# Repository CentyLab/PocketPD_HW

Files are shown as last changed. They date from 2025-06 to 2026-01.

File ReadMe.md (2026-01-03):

Shield: [][cc-by-sa]

This work is licensed under a
[Creative Commons Attribution-ShareAlike 4.0 International License][cc-by-sa].

[][cc-by-sa]

[cc-by-sa]: http://creativecommons.org/licenses/by-sa/4.0/
[cc-by-sa-image]: https://licensebuttons.net/l/by-sa/4.0/88x31.png
[cc-by-sa-shield]: https://img.shields.io/badge/License-CC%20BY--SA%204.0-lightgrey.svg

# Quick links
- PocketPD's Firmware - [GitHub](https://github.com/CentyLab/PocketPD)
- PocketPD's Project Page - [Hackaday.io](https://hackaday.io/project/194295-pocketpd-usb-c-portable-bench-power-supply)
- CentyLab website - [CentyLab.com](https://centylab.com)
- CrowdSupply Page - [CrowdSupply.com](https://www.crowdsupply.com/centylab/pocketpd)

# Hardware Overview
- Design Files - .kicad_*
	- KiCad design files
- Gerber files - _Gerber.zip; _Gerber.pdf
    - PCB copper and drill file for fabrication
- Schematic file - _Schematic.pdf
    - Schematic in PDF format
- BOMs - _bom.cvs
    - Bill of material for the PCBA and also the unit assembly for additional parts
- 3Ds files
    - Model ready for 3D printing for housing and encoder knob. You can view the models online directly on GitHub. Else, check out free online viewer [3dviewer.net](https://3dviewer.net/)
	- 3D model for the whole PocketPD PCB and Connector if you would like to model your own case.

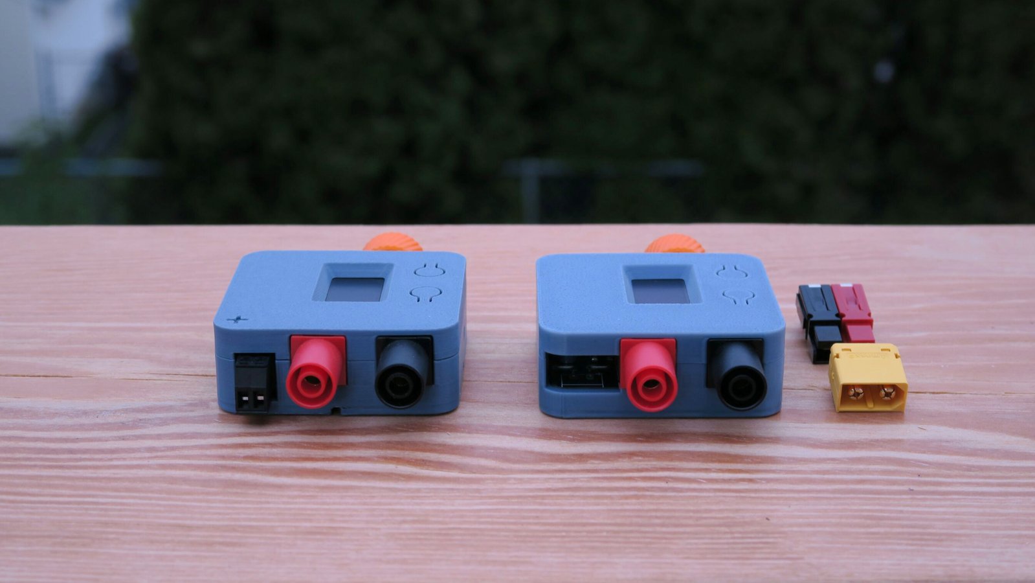
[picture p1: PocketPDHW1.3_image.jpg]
BothVersionImage


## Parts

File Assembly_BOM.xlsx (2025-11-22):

Description | Quatity | Part # | Estimate price | Note | Suggested Supplier
M2 x 4mm, flat head | 4 |  |  | Self taping, pan head or counter sunk head both work
M2 x 10mm, flat head | 4 |  |  | Self taping, pan head or counter sunk head both work
Neodium N35 Magnet 15x5mm, flat disc | 1 |  |  | No glue is needed
Thermal double-sided tape, 15x5mm | 1 |  |  | No exact dimension is needed. Need to cover most of the magnet
OLED WHITE screen 0.96 inch I2C, exact dimension + pin layout attached | 1 |  | 3 |  | https://www.aliexpress.us/item/3256806076593949.html
EC11J-5DM20P1ZY15F7, Encoder | 1 | EC11J | 1.65 |  | https://www.aliexpress.us/item/3256807905633617.html
1x2P Black Plug P=3.81mm Pluggable System Terminal Block ROHS | 1 | C430322 (https://www.lcsc.com/product-detail/Pluggable-System-Terminal-Block_DORABO-DB2EK-3-81-2P-BK-S_C430322.html) | 0.1828 | LCSC/Mouser/Digikey
Anderson Powerpole PR45 | 1 | ASMPR45-1X2-RK | 3.95 | Order on Mouser/Digikey
XT60 Male Right Angle | 1 | XT60PW-M | 0.58
Encoder Knob | 1 |  |  | 3D printed, PETG/ABS, Orange
Top case | 1 |  |  | 3D printed, PETG/ABS, Dark Gray or Blue Gray
Bottom case | 1 |  |  | 3D printed, PETG/ABS, Dark Gray or Blue Gray

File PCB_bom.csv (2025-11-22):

Designator | Footprint | Quantity | Value | LCSC Part #
C1, C10, C11, C12, C14, C19, C2, C21, C24, C26, C4, C5, C7, C8, C9 | 402 | 15 | 100nF | C1525
C13, C18, C6 | 402 | 3 | 2.2uF | C12530
C15, C22, C23 | 1210 | 3 | 10u | C138687
C16, C20 | 402 | 2 | 30pF | C1570
C17 | CP_Elec_6.3x7.7 | 1 | 100u | C178560
C27, C3 | 805 | 2 | 1u | C28323
C28, C30 | 603 | 2 | 100n | C14663
D1 | SON50P100X255X50-10N | 1 | TPD4E05U06DQAR | C138714
D2 | D_SMA | 1 | D_Schottky | C8678
D3, D6 | D_SMA | 2 | D_TVS | C19077540
D5 | 603 | 1 | RED | C2286
J1 | USB_C | 1 | USB_C_Receptacle | C963411
J4 | Conn_OLED_PocketPD | 1 | OLED | C20071191
J6 | Banana_Cliff_FCR7350R_S16N-PC_Horizontal | 1 | BananaP | C7437326
J8 | Banana_Cliff_FCR7350B_S16N-PC_Horizontal | 1 | BananaN | C7437327
R1 | 1206 | 1 | 5mR | C2988648
R10, R11 | 402 | 2 | 27R | C138021
R12, R18, R20, R26, R27, R29, R30 | 402 | 7 | 1k | C11702
R13, R14, R25 | 402 | 3 | 10R | C25077
R15, R16, R17, R19, R22, R28, R6, R7, R9 | 402 | 9 | 10k | C25744
R2, R21, R23, R24, R3, R4, R5, R8 | 402 | 8 | 5.1k | C25905
SW1 | RotaryEncoder_EC11B_SW_Horizontal | 1 | RotaryEncoder_Switch
SW2 | Button_6.2x6.2x12mm | 1 | SW_Select | C2762973
SW4 | Button_6.2x6.2x12mm | 1 | SW_OutPut | C2762973
SW5 | Button-SMD_TS24CA | 1 | SW_Boot | C692458
TH1 | 402 | 1 | Thermistor_NTC | C77131
U1, U6 | VQFN-HR-16 | 2 | LM73100 | C3210761
U2 | QFN-24-1EP_4x4mm_P0.5mm_EP2.6x2.6mm | 1 | AP33772 | C5244513
U3 | QFN-56-1EP_7x7mm_P0.4mm_EP3.2x3.2mm | 1 | RP2040 | C2040
U4 | SOT-23-5 | 1 | AP2204K-3.3 | C112032
U5 | 8-USON | 1 | W25Q16JVUXIQ_TR | C2843335
U7 | VSSOP-10_3x3mm_P0.5mm | 1 | INA226 | C49851
U8 | SOT-353_SC-70-5 | 1 | 74LVC1G17 | C10425
Y1 | Crystal_SMD_3225-4Pin_3.2x2.5mm | 1 | 12MHz | C133334

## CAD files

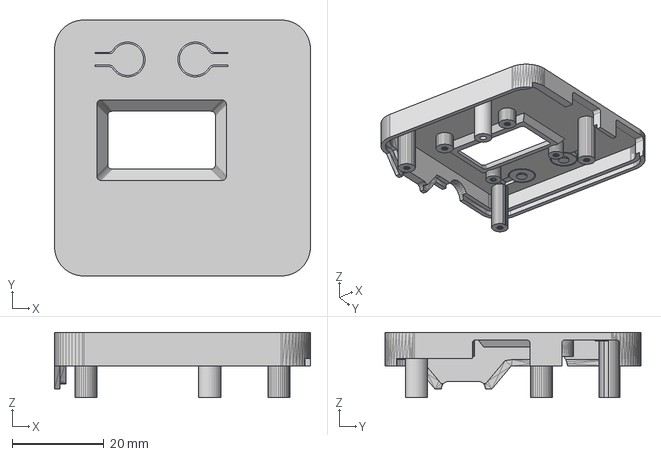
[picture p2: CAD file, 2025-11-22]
AnderonXT60_SKU2/Top_Anderson-XT60.step
55.8 x 55.8 x 14.2 mm

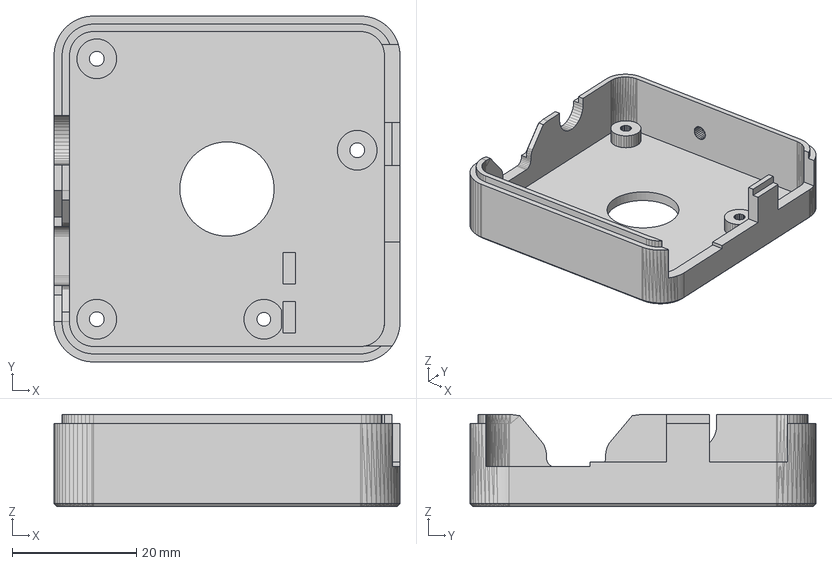
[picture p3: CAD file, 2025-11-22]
AnderonXT60_SKU2/Bottom_Anderson-XT60.step
55.8 x 55.8 x 14.9 mm

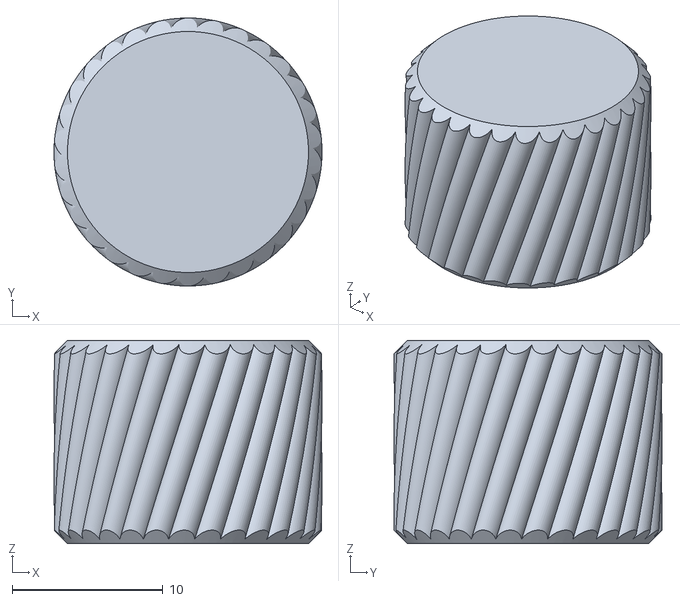
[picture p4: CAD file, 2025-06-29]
AnderonXT60_SKU2/Knob.stl
17.8 x 17.8 x 13.5

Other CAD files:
ScrewTerminal_SKU1/PocketPD_BOT_ScrewTerminal.step
ScrewTerminal_SKU1/PocketPD_TOP_ScrewTerminal.step

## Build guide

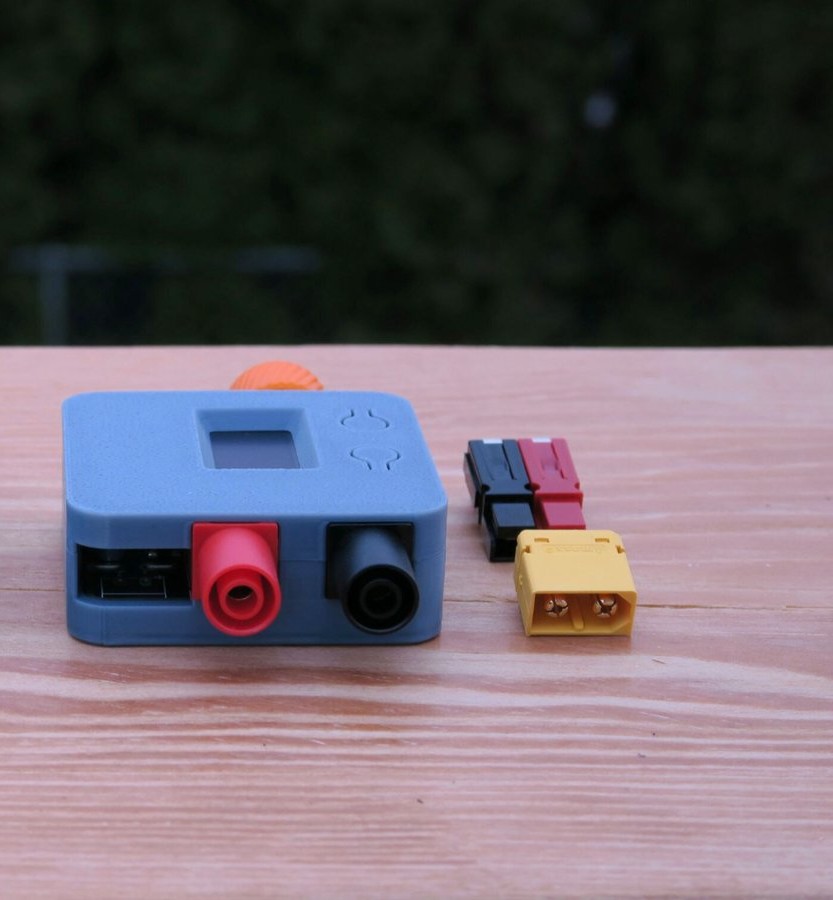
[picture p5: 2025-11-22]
AnderonXT60_SKU2/AndersonXT60_complete_assembly.jpg

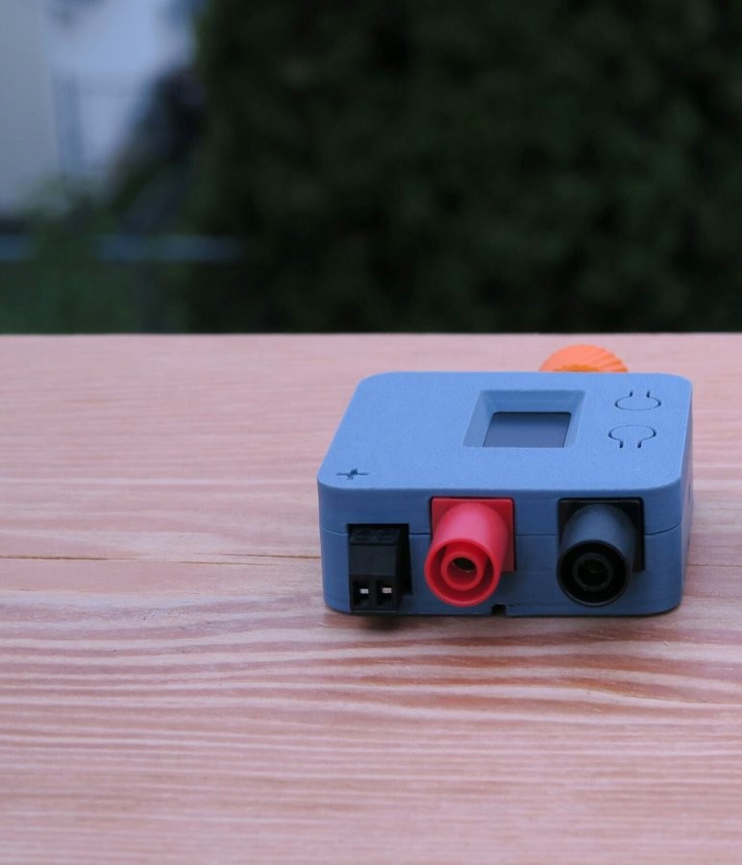
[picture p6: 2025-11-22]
ScrewTerminal_SKU1/ScrewTerm_complete_assembly.jpg

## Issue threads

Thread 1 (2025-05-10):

"pick and place" file

warped-pipe, 2025-05-10:
is this a file that i can make for myself by opening these in kicad? it'd be nice to have, to make ordering via jlpcb easy..

warped-pipe, 2025-05-10:
thank you so much for making the hardware open!

Johaan1314, 2025-05-11:
The cost of ordering and using extended parts from JLCPCB is not worth it. It consists of more than 10 extended parts which is at least $30 of extended part fees, on top of part fees, SMT set-up fees, etc. And that's already the best assumption that all the parts can be found in JLCPCB's extended part list.

It would be great if they can order the kicad SCH and PCB files so one can upload to JLCPCB to verify it for themselves, but I'm fairly certain the costs won't workout for small volumes. It's going to be cheaper to just order from the original website at https://lectronz.com/products/pocketpd

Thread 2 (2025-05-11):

Query: Why Dual LM73100?

Johaan1314, 2025-05-11:
Hi,

not an issue, but I'm curious as to why there are two LM73100? each LM73100 already contains 2 FET for reverse current protection, and each can take the 5A which is the max for PPS right?

Thanks!

CentyLab, 2025-05-11:
The LM73100 get hot fast if pulling 5A through. It get to more than 80C for
one, so we double them up to spread the heat and reduce voltage drop.

The short circuit protection still work with 2 IC in parallel which is nice.

-Centy

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

Johaan1314, 2025-05-11:
Thank you very much for sharing! =)

Closed 2025-05-11.

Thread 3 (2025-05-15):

device models

Willofswan, 2025-05-15:
Thank you very much for sharing. I would like to make one myself. Can you tell me the specific device models of TH1, SW2, SW4?I‘m unable to obtain specific information from the BOM, thank you

Closed 2025-05-15.

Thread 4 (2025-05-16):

[Information] Added a DC barrel plug as _additional_ output into the case.

dreirund, 2025-05-16:
Ahoj,

to let you know: I managed to fit in an additional output connector -- a barrel plug DC connector -- to my PocketPD (Hardware version 1.0):

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

(Note that the barrel plug might not be rated at 5A but only at 2A).

Regards!

CentyLab, 2025-05-16:
@dreirund We are glad that you were able to mod it to your liking!

dreirund, 2025-05-18:
Some suggestions:

* Add somewhere a "user modifications" gallery, where people can share their modifications (wiki?) or where you show modifications which users have made and sent you.

* Maybe in a future PCB revision you can add solder points to the PCB for exactly this kind of modification?

* And maybe, since it is now "proven" that the connector can be added without sacrificing any other connector, you can actually add it in a next design/ offer to add it as an option? (however, the connector won't be soldered to the PCB but screw-mounted to the case, which requires more manual soldering.)

  If you are concerned with the power rating, maybe adding a "[polyfuse](https://en.wikipedia.org/wiki/Resettable_fuse)" and/ or using the sense pin of the barrel plug connector to make the firmware setting an appropriate power limit if a barrel plug is plugged in -- but I have also seen higher power barrel sockets so far, installed in devices (small computers).

Regards!

LIVESKILLER, 2025-08-12:
> 我们很高兴您能够根据自己的喜好对其进行修改！

    I really like your design. Since 0402 components are too difficult to solder, I want to have the PCB assembled by the manufacturer. Could you please provide the coordinate file? Thank you very much!

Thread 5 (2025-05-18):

PD_INT pin is not connected in pcb

ninjaWw, 2025-05-18:
According to the published schematic, pin 36 of RP2040 is defined as PD_INT, and pin 9 of AP33772 is also PD_INT, but these two pins are not connected in the PCB. Is this an error?

CentyLab, 2025-05-19:
Hi @ninjaWw,
This was an oversight. The AP33772 library doesn't utilize the INT pin so we didn't check for connection. At this point, we won't be able to change the current version of the hardware as it already rolled out to production. Luckily, this missing pin won't impact the features provided by the PocketPD firmware.
We have noted the missing connection for future revision if there is more major change to the hardware.

dreirund, 2025-05-19:
> [pin 9 of AP33772 is also PD_INT](#issue-3071221435)

The [datasheet](https://www.diodes.com/datasheet/download/AP33772.pdf) calls pin 9 of AP33772 only "GPIO3". And yes, in the description it says "*For Interrupt Usage*", and further:

> ***I2C Support***
> *The I2C functions of the AP33772 are enabled by three pins—SDA (Pin 4—I2C data), SCL (Pin 5—I2C Clock), and GPIO3 (Pin 9—Interrupt). The host MCU of the TCD, functioning as the I2C master, writes proper contents to the relevant I2C register of the AP33772, working as an I2C slave device, to specify desired power profiles and various protection features. It also accesses the AP33772 for various statuses to take proper actions and maintain normal functions of the TCD during the charging process. \[&hellip;\]*

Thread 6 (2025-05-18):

[Question] What are advantages and drawbacks of 5 mOhm current sensing resistor instead of 10 mOhm?

dreirund, 2025-05-18:
Ahoj,

what benefit and drawback you actually observed with changing the current sensing resistor from 10mOhm to 5mOhm in hardware revision 1.1?

At 5A current, 10 mOhm gives a voltage drop of 0.05V (5mOhm of 0.025V). I suppose this is much less than what the resistance of connectors (and cables) give, _and_ there is also the "ideal diode" + switch LM73100, which has something like 20..30 mOhm of switched-on resistance (or 10..15 mOhm in case you have put the two switches in parallel).

So, what actually are the "real world" advantages, and drawbacks, of 5 mOhm instad of 10 mOhm of this resistor?

I am asking because I could add another 10mOhm SMD resistor on top of the existing one, thus making it 5 mOhm.

(I can think off that 5 mOhm makes current sensing less accurate.)

Regards!

dreirund, 2025-05-19:
> *[With 5mOhm we got a current resolution at 0.5mA \[&hellip;\]](#issuecomment-2889953775)*
> *[We have selected 5mOhm instead of 10mOhm is to reduce the heat generated.](#issuecomment-2889953775)*

Thanks for the answer and clarification!

Closed 2025-05-19.

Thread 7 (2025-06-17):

OVLO of LM7310 connected to GND

Johaan1314, 2025-06-17:
Am hoping to learn from your design. According to the datasheet for LM7310, OVLO (overvoltage lockout) should be connected to a resistor divider between Vin and GND to set the overvoltage protection. But in the schematics OVLO is connected to ground instead. Can you help to educate me please?

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

CentyLab, 2025-06-17:
Hi,
The LM7310 require OVLO to be low enough, and EN high enough to activate
the switch. We soly want the microcontroller to have control of the IC so
we GND the OVLO, allow just EN pin as toggle for the circuit.

If the power source is USBC conpliance, there is a very low chance that
VBUS exceed 20V. And transient (spike higher than 20V) is designed to be
clamped down by TVS diode around input and ouput.
-Centy

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

Closed 2025-06-17.

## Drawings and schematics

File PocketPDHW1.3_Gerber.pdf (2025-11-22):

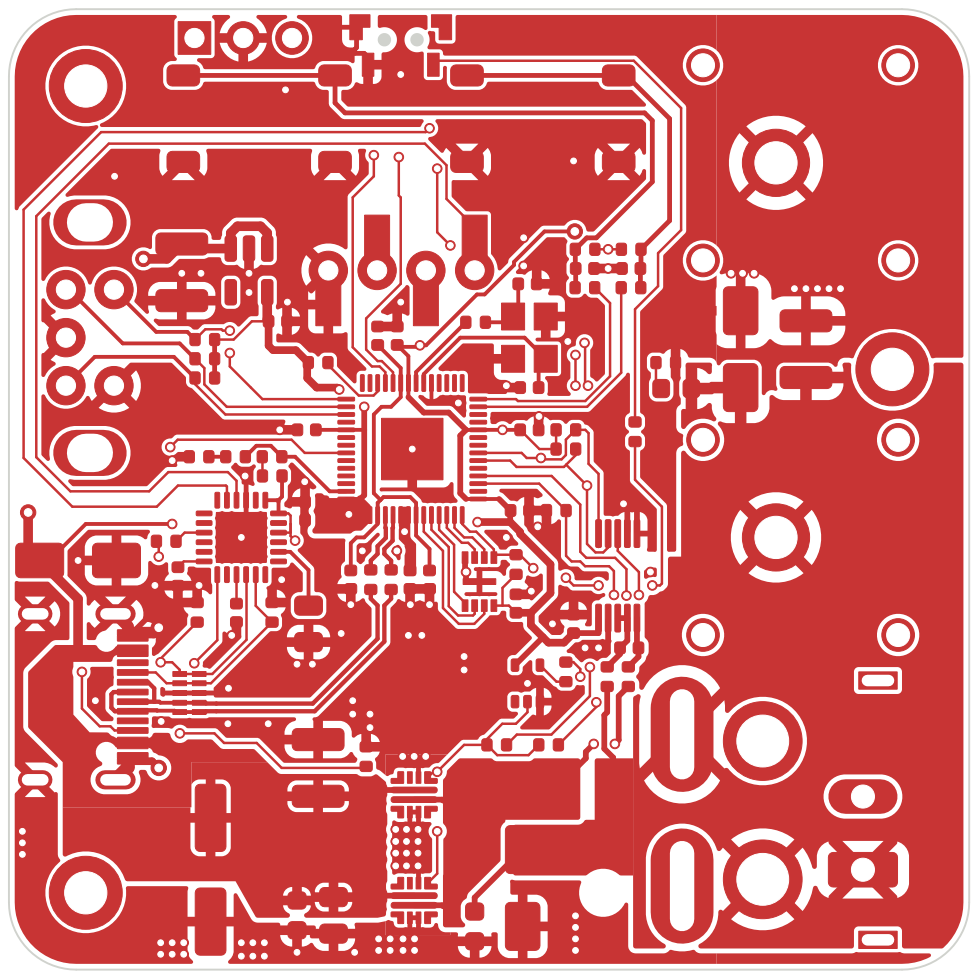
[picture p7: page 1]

Id: 1/7 Title: File: PicoPDSupply.kicad_pcb Sheet:

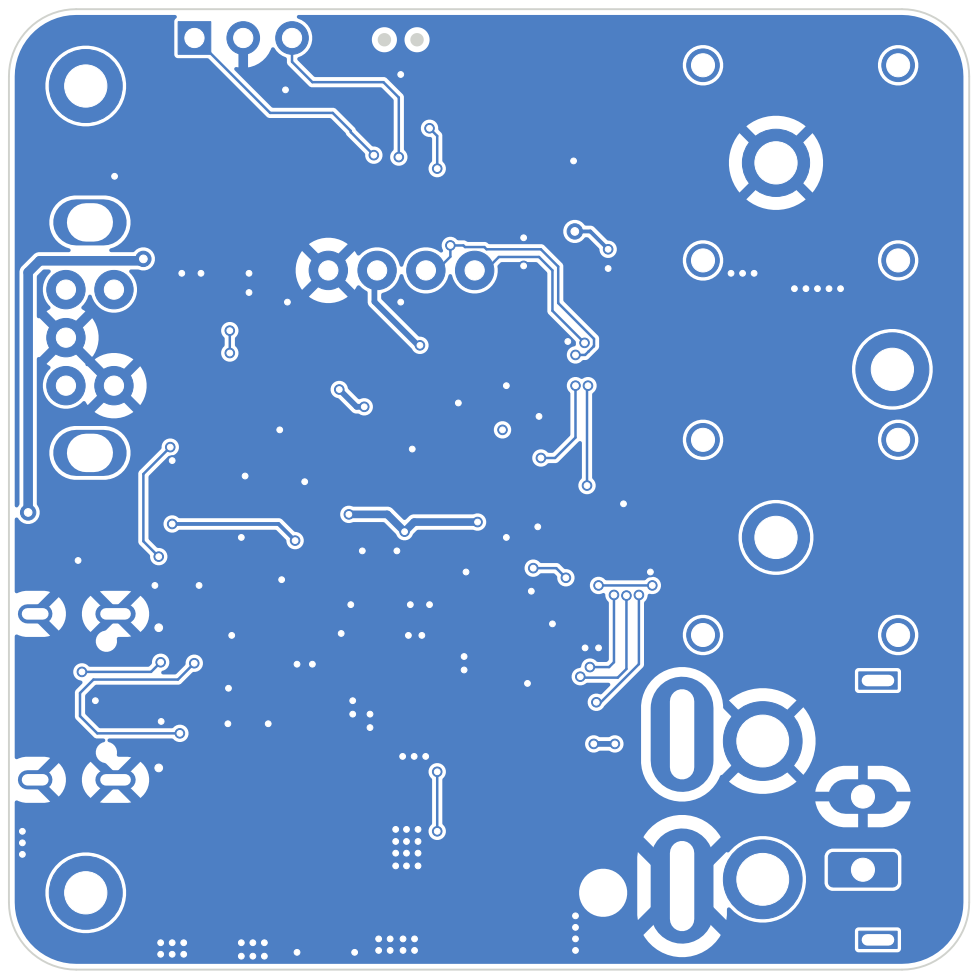
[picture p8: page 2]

Id: 2/7 Title: File: PicoPDSupply.kicad_pcb Sheet:

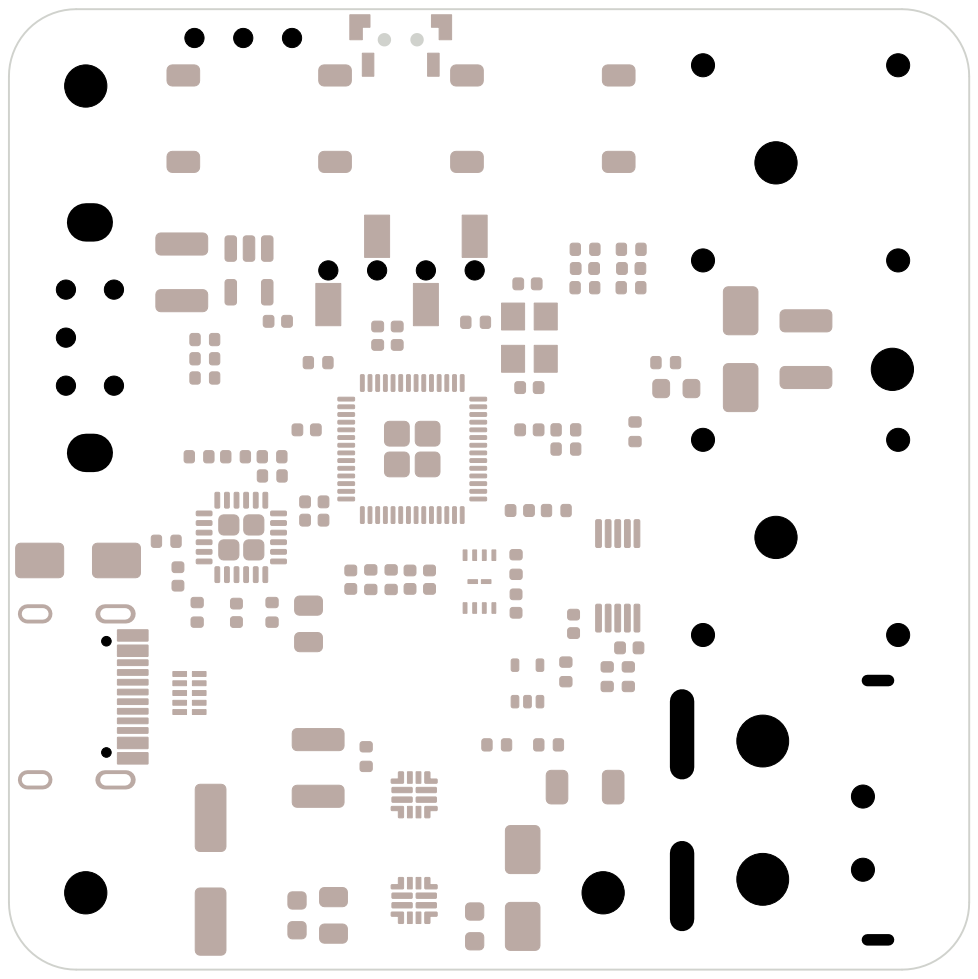
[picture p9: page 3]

Id: 3/7 Title: File: PicoPDSupply.kicad_pcb Sheet:

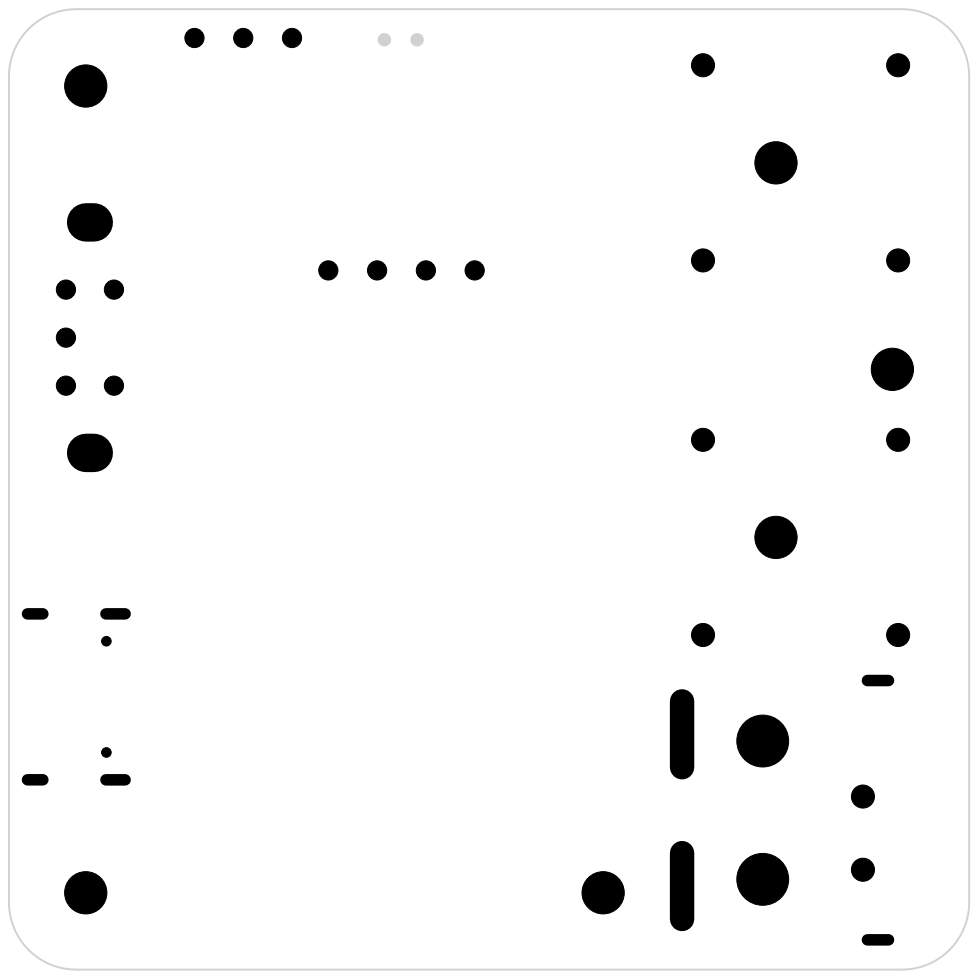
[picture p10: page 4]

Id: 4/7 Title: File: PicoPDSupply.kicad_pcb Sheet:

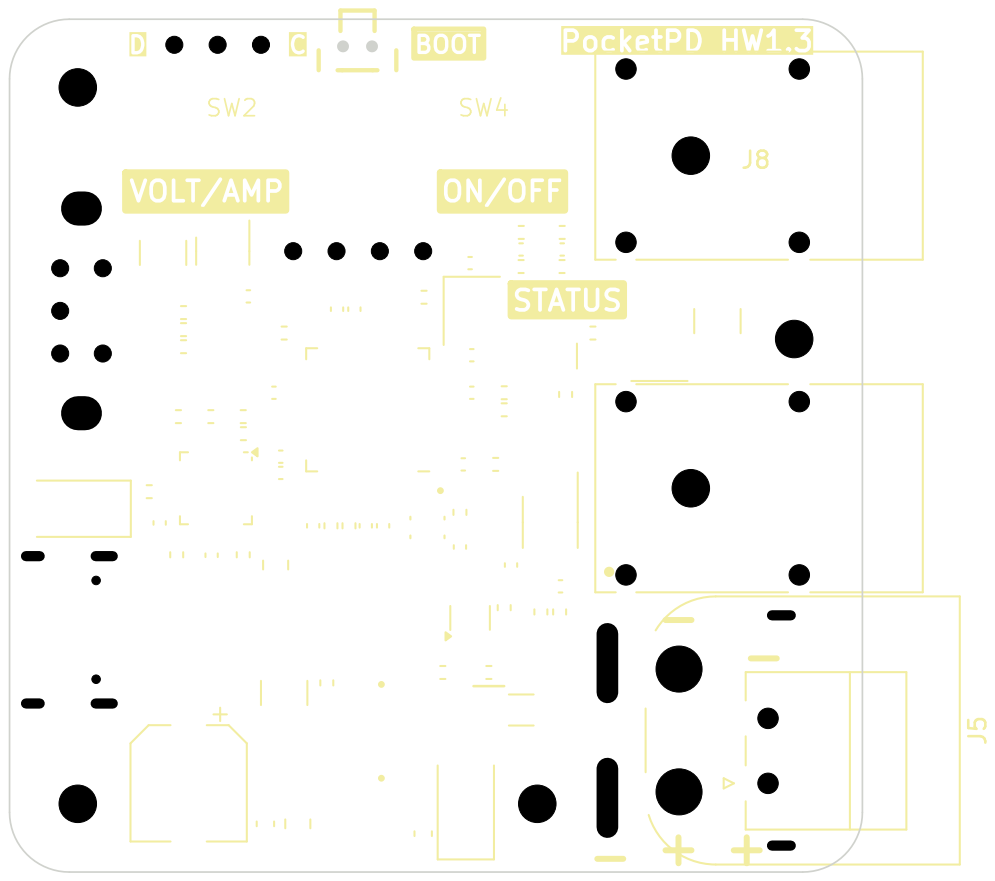
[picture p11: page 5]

Id: 5/7 Title: File: PicoPDSupply.kicad_pcb Sheet:

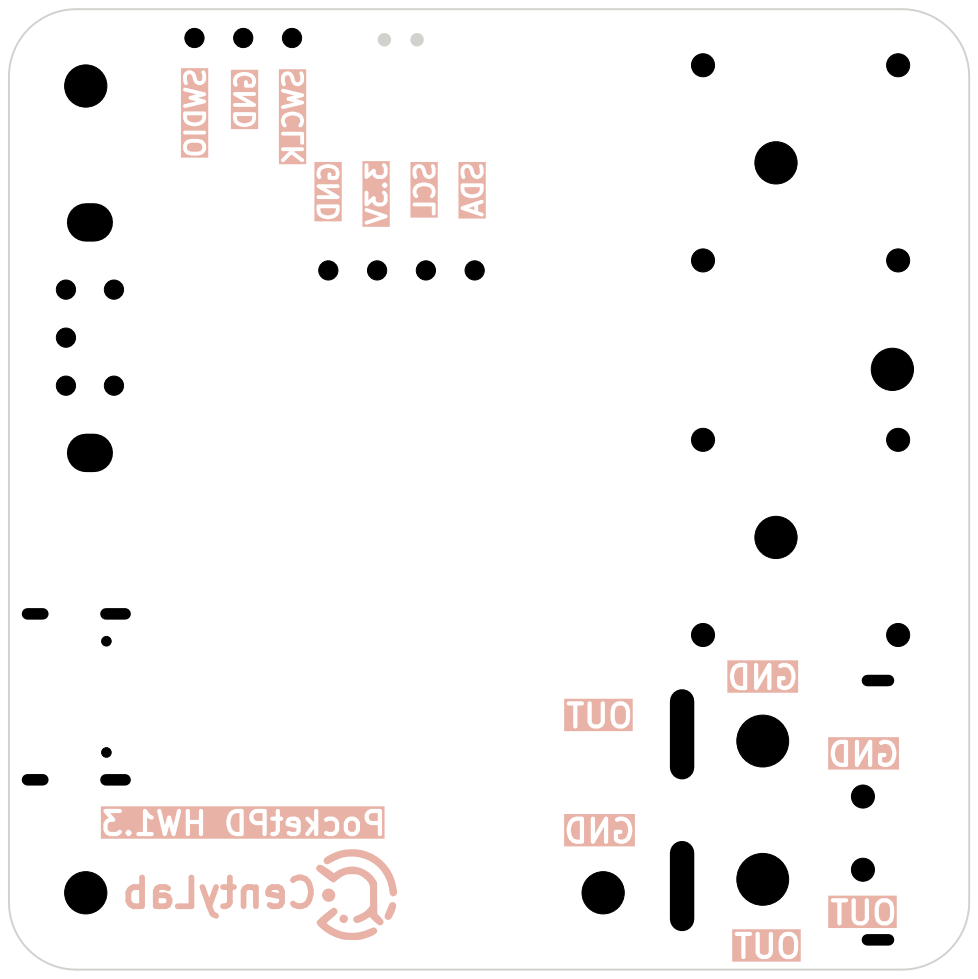
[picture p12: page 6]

Id: 6/7 Title: File: PicoPDSupply.kicad_pcb Sheet: CentyLab

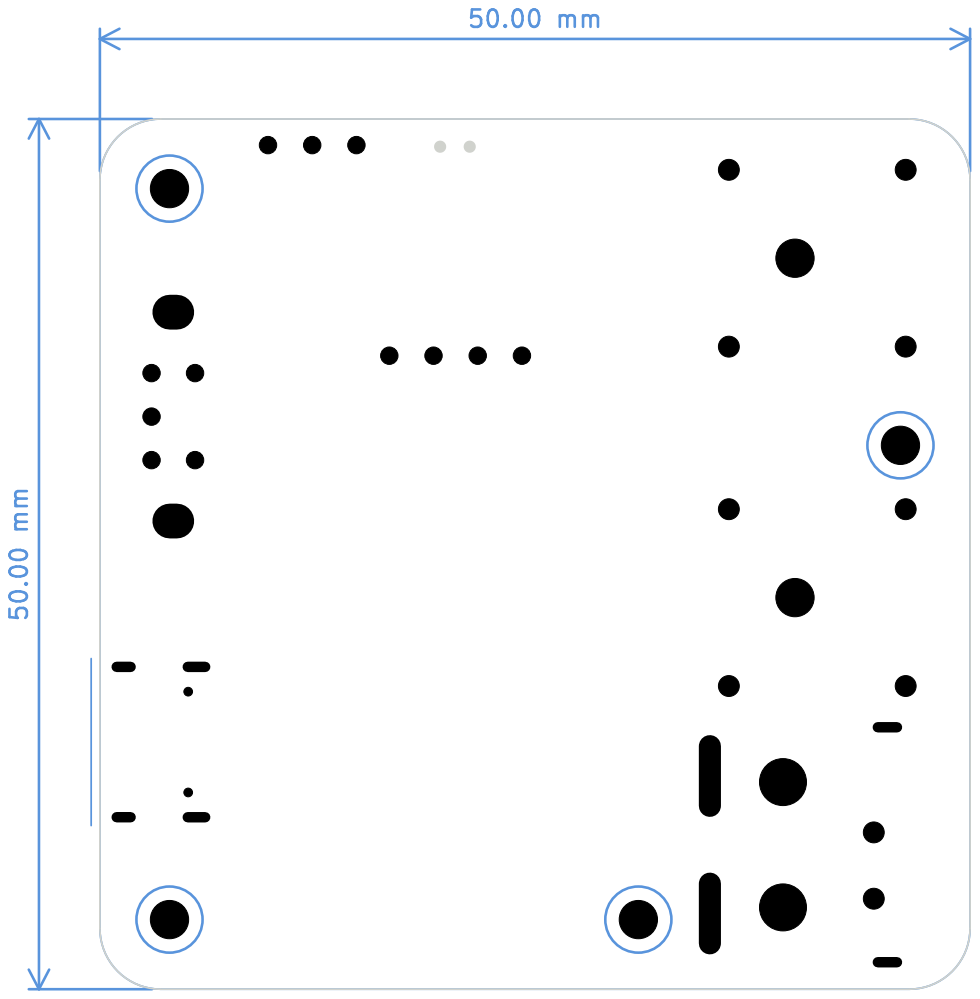
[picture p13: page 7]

Id: 7/7 Title: File: PicoPDSupply.kicad_pcb Sheet:

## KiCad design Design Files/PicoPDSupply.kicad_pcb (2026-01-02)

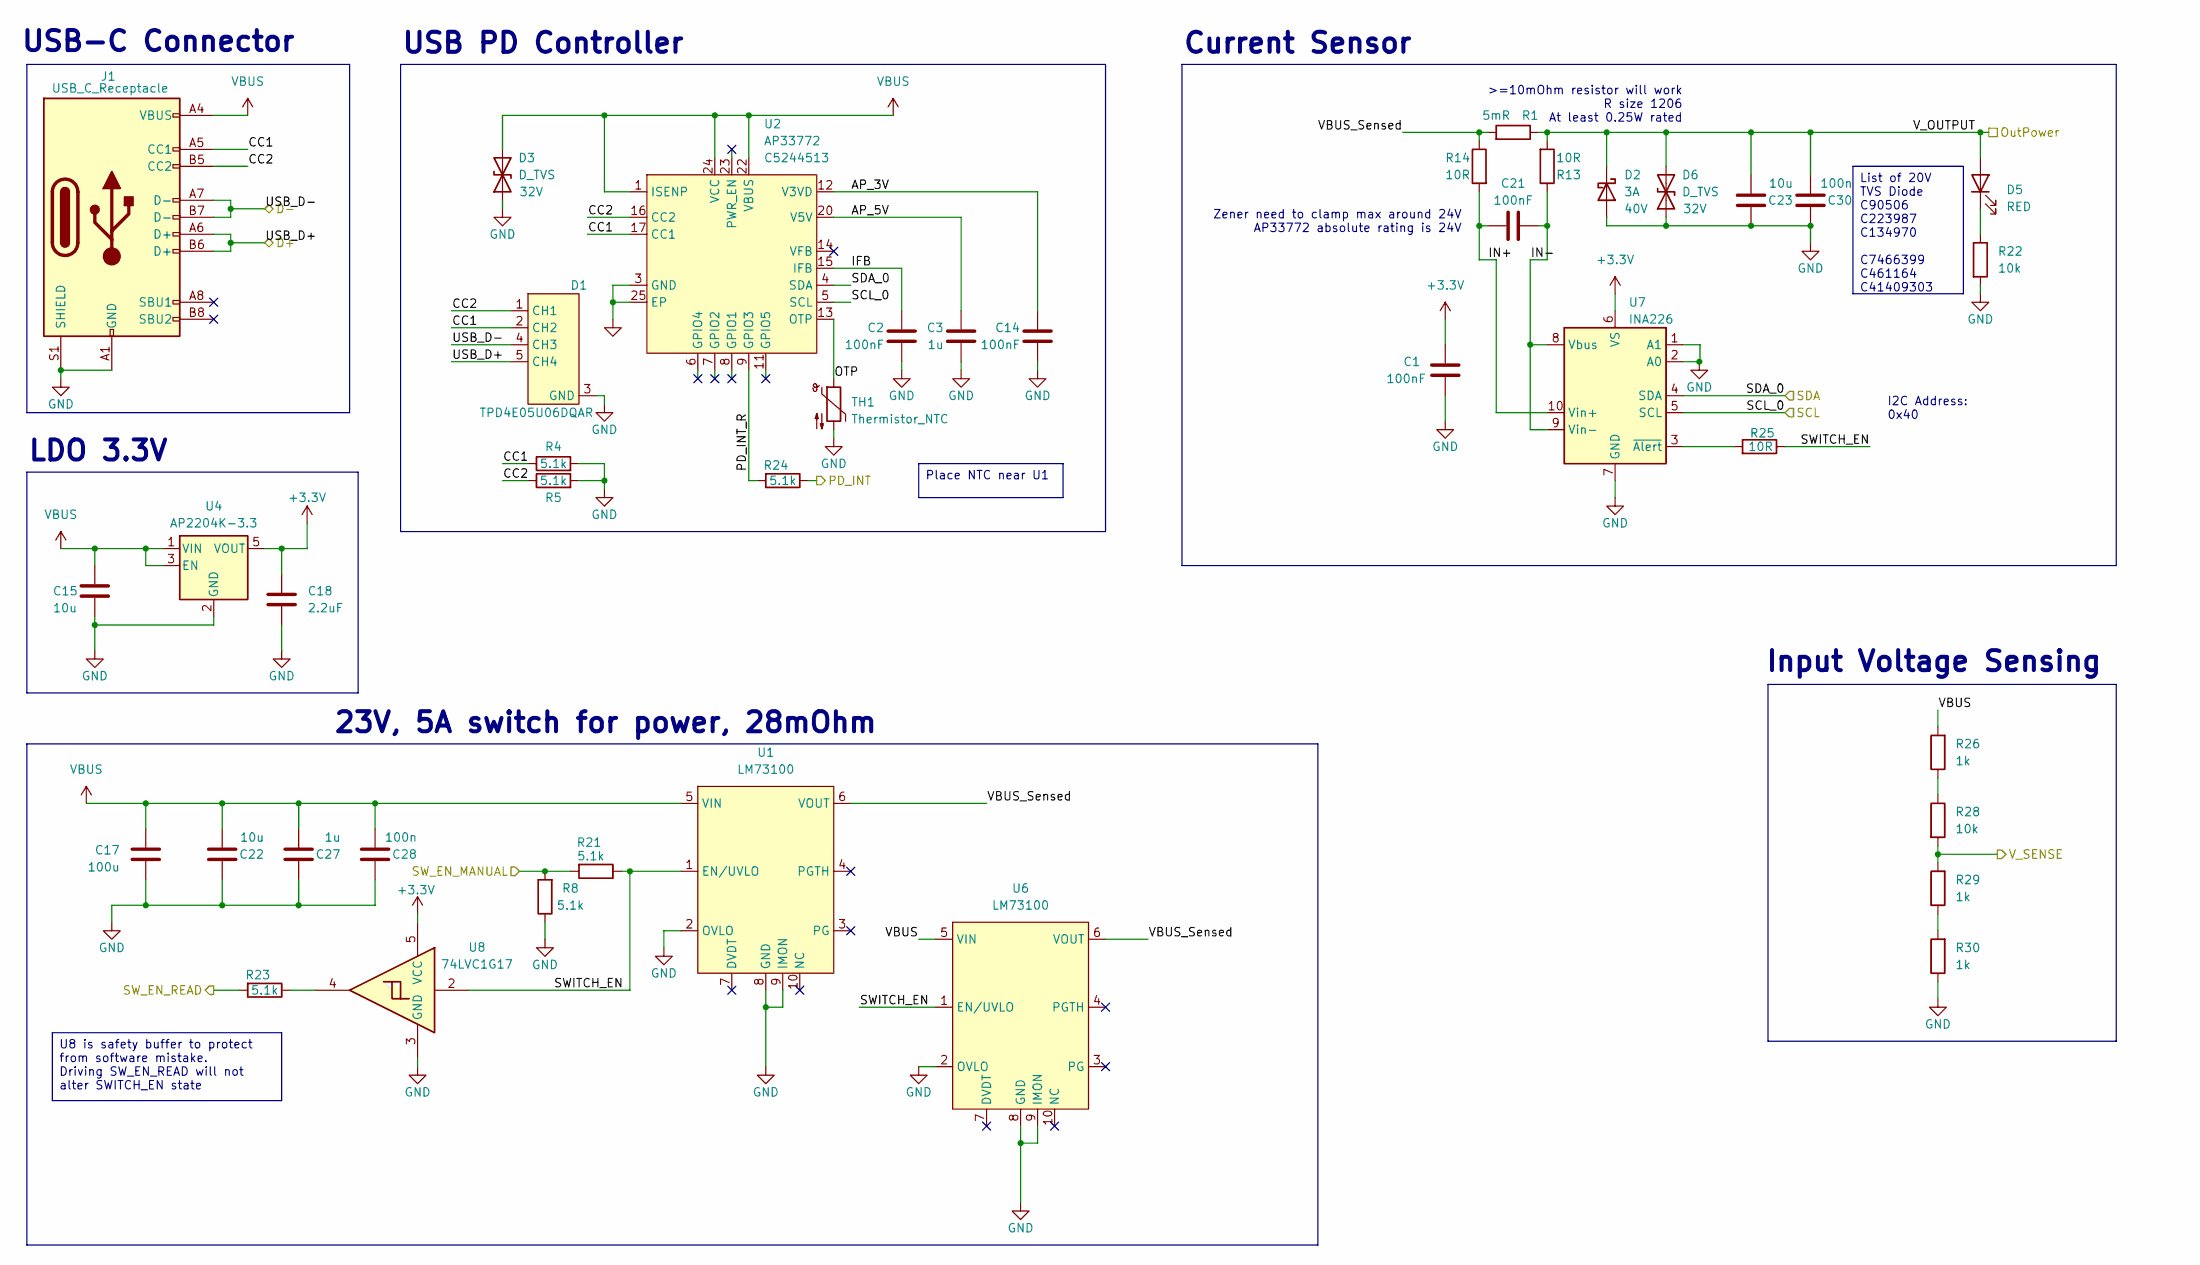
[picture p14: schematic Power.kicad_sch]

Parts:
C1, C2, C14, C21: 100nF; C_0402_1005Metric; LCSC C1525
C3, C27: 1u; C_0805_2012Metric; LCSC C28323
C15, C22, C23: 10u; C_1210_3225Metric; LCSC C138687
C17: 100u; CP_Elec_6.3x7.7; Manufacture # EEEFK1V101XP; LCSC C178560
C18: 2.2uF; C_0402_1005Metric; LCSC C12530
C28, C30: 100n; C_0603_1608Metric; LCSC C14663
D1: TPD4E05U06DQAR; SON50P100X255X50-10N; LCSCAlternative1 C478014
D2: D_Schottky; D_SMA; Voltage 40V; LCSC C8678
D3, D6: D_TVS; D_SMA; Clamp Voltage 32V; LCSC C19077540
D5: RED; LED_0603_1608Metric; LCSC C2286
J1: USB_C_Receptacle; USB_C_GSwitch; LCSC C963411
R1: 5mR; R_1206_3216Metric; LCSC C2988648
R4, R5, R8, R21, R23, R24: 5.1k; R_0402_1005Metric; LCSC C25905
R13, R14, R25: 10R; R_0402_1005Metric; LCSC C25077
R22, R28: 10k; R_0402_1005Metric; LCSC C25744
R26, R29, R30: 1k; R_0402_1005Metric; LCSC C11702
TH1: Thermistor_NTC; R_0402_1005Metric; LCSC C77131
U1, U6: LM73100; VQFN-HR-16; LCSC C3210761
U2: AP33772; QFN-24-1EP_4x4mm_P0.5mm_EP2.6x2.6mm; LCSC C5244513
U4: AP2204K-3.3; SOT-23-5; JLCPCB Rotation Offset 180
U7: INA226; VSSOP-10_3x3mm_P0.5mm; LCSC C49851
U8: 74LVC1G17; SOT-353_SC-70-5; LCSC C10425

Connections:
+3.3V: C1.1, C18.1, U4.5 (VOUT), U7.6 (VS), U8.5 (VCC); also elsewhere on the board
/Connection/V_OUTPUT: C23.2, C30.2, D2.1 (K), D5.2 (A), D6.2 (A2), R1.1, R13.2; also elsewhere on the board
/MicroController/ADC3: R28.2, R29.2; also elsewhere on the board
/MicroController/GPIO1: R8.2, R21.2; also elsewhere on the board
/MicroController/GPIO2: R23.2; also elsewhere on the board
/MicroController/GPIO24: R24.1; also elsewhere on the board
/MicroController/USB_D+: D1.5 (CH4), D1.6, J1.A6 (D+), J1.B6 (D+); also elsewhere on the board
/MicroController/USB_D-: D1.4 (CH3), D1.7, J1.A7 (D-), J1.B7 (D-); also elsewhere on the board
/Power/AP_3V: C14.1, U2.12 (V3VD)
/Power/AP_5V: C3.1, U2.20 (V5V)
/Power/CC1: D1.2 (CH2), D1.9, J1.A5 (CC1), R4.1, U2.17 (CC1)
/Power/CC2: D1.1 (CH1), D1.10, J1.B5 (CC2), R5.1, U2.16 (CC2)
/Power/IFB: C2.1, U2.15 (IFB)
/Power/IN+: C21.2, R14.2, U7.10 (Vin+)
/Power/IN-: C21.1, R13.1, U7.8 (Vbus), U7.9 (Vin-)
/Power/OTP: TH1.1, U2.13 (OTP)
/Power/PD_INT_R: R24.2, U2.9 (GPIO3)
/Power/SCL_0: U2.5 (SCL), U7.5 (SCL); also elsewhere on the board
/Power/SDA_0: U2.4 (SDA), U7.4 (SDA); also elsewhere on the board
/Power/SWITCH_EN: R21.1, R25.1, U1.1 (EN/UVLO), U6.1 (EN/UVLO), U8.2
/Power/VBUS_Sensed: R1.2, R14.1, U1.6 (VOUT), U6.6 (VOUT)
GND: C1.2, C2.2, C3.2, C14.2, C15.2, C17.2, C18.2, C22.1, C23.1, C27.1, C28.1, C30.1, D1.3 (GND), D1.8 (GND), D2.2 (A), D3.1 (A1), D6.1 (A1), J1.A1 (GND), J1.A12 (GND), J1.B1 (GND), J1.B12 (GND), J1.S1 (SHIELD), R4.2, R5.2, R8.1, R22.2, R30.1, TH1.2, U1.2 (OVLO), U1.8 (GND), U1.9 (IMON), U2.3 (GND), U2.25 (EP), U4.2 (GND), U6.2 (OVLO), U6.8 (GND), U6.9 (IMON), U7.1 (A1), U7.2 (A0), U7.7 (GND), U8.3 (GND); also elsewhere on the board
unnamed: D5.1 (K), R22.1
unnamed: R23.1, U8.4
unnamed: R26.1, R28.1
unnamed: R29.1, R30.2
unnamed: R25.2, U7.3 (~Alert)
VBUS: C15.1, C17.1, C22.2, C27.2, C28.2, D3.2 (A2), J1.A4 (VBUS), J1.A9 (VBUS), J1.B4 (VBUS), J1.B9 (VBUS), R26.2, U1.5 (VIN), U2.1 (ISENP), U2.22 (VBUS), U2.24 (VCC), U4.1 (VIN), U4.3 (EN), U6.5 (VIN)

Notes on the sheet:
Input Voltage Sensing
>=10mOhm resistor will work R size 1206 At least 0.25W rated
Zener need to clamp max around 24V AP33772 absolute rating is 24V
USB-C Connector
Current Sensor
USB PD Controller
23V, 5A switch for power, 28mOhm
I2C Address: 0x40
LDO 3.3V
Place NTC near U1
List of 20V TVS Diode C90506 C223987 C134970 C7466399 C461164 C41409303
U8 is safety buffer to protect from software mistake. Driving SW_EN_READ will not alter SWITCH_EN state

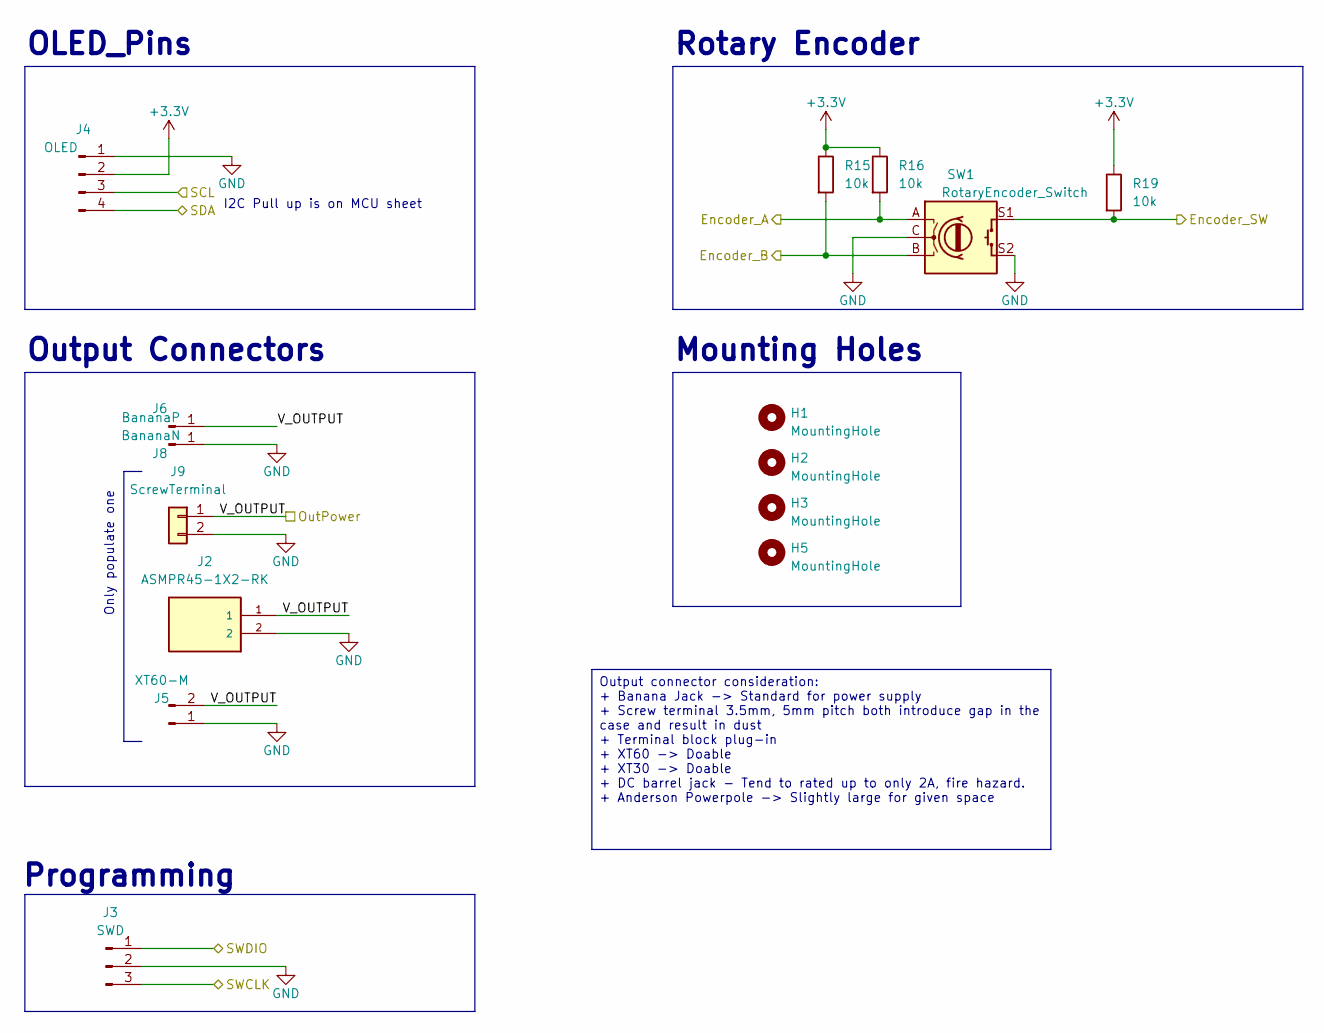
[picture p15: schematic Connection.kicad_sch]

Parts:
H1: MountingHole; MountingHole_2.2mm_M2_DIN965
H2, H3, H5: MountingHole; MountingHole_2.2mm_M2_DIN965_Pad
J2: ASMPR45-1X2-RK; Conn_ASMPR45-1X2-RK
J3: SWD; PinHeader_1x03_P2.54mm_Vertical
J4: OLED; Conn_OLED_PocketPD; LCSC C20071191
J5: XT60-M; AMASS_XT60PW-M_1x02_P7.20mm_Horizontal
J6: BananaP; Banana_Cliff_FCR7350R_S16N-PC_Horizontal; LCSC C7437326
J8: BananaN; Banana_Cliff_FCR7350B_S16N-PC_Horizontal; LCSC C7437327
J9: ScrewTerminal; PhoenixContact_MC_1,5_2-G-3.81_1x02_P3.81mm_Horizontal; LCSC C5259145
R15, R16, R19: 10k; R_0402_1005Metric; LCSC C25744
SW1: RotaryEncoder_Switch; RotaryEncoder_EC11B_SW_Horizontal; LCSC C9900176956

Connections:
+3.3V: J4.2, R15.1, R16.1, R19.1; also elsewhere on the board
/Connection/V_OUTPUT: J2.1, J5.2, J6.1, J9.1; also elsewhere on the board
/MicroController/GPIO18: R19.2, SW1.S1; also elsewhere on the board
/MicroController/GPIO19: R16.2, SW1.A; also elsewhere on the board
/MicroController/GPIO20: R15.2, SW1.B; also elsewhere on the board
/MicroController/SWCLK: J3.3; also elsewhere on the board
/MicroController/SWDIO: J3.1; also elsewhere on the board
/Power/SCL_0: J4.3; also elsewhere on the board
/Power/SDA_0: J4.4; also elsewhere on the board
GND: J2.2, J3.2, J4.1, J5.1, J8.1, J9.2, SW1.C, SW1.S2; also elsewhere on the board

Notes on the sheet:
Only populate one
Mounting Holes
Output Connectors
Rotary Encoder
OLED_Pins
Programming
I2C Pull up is on MCU sheet
Output connector consideration: + Banana Jack -> Standard for power supply + Screw terminal 3.5mm, 5mm pitch both introduce gap in the case and result in dust + Terminal block plug-in + XT60 -> Doable + XT30 -> Doable + DC barrel jack - Tend to rated up to only 2A, fire hazard. + Anderson Powerpole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

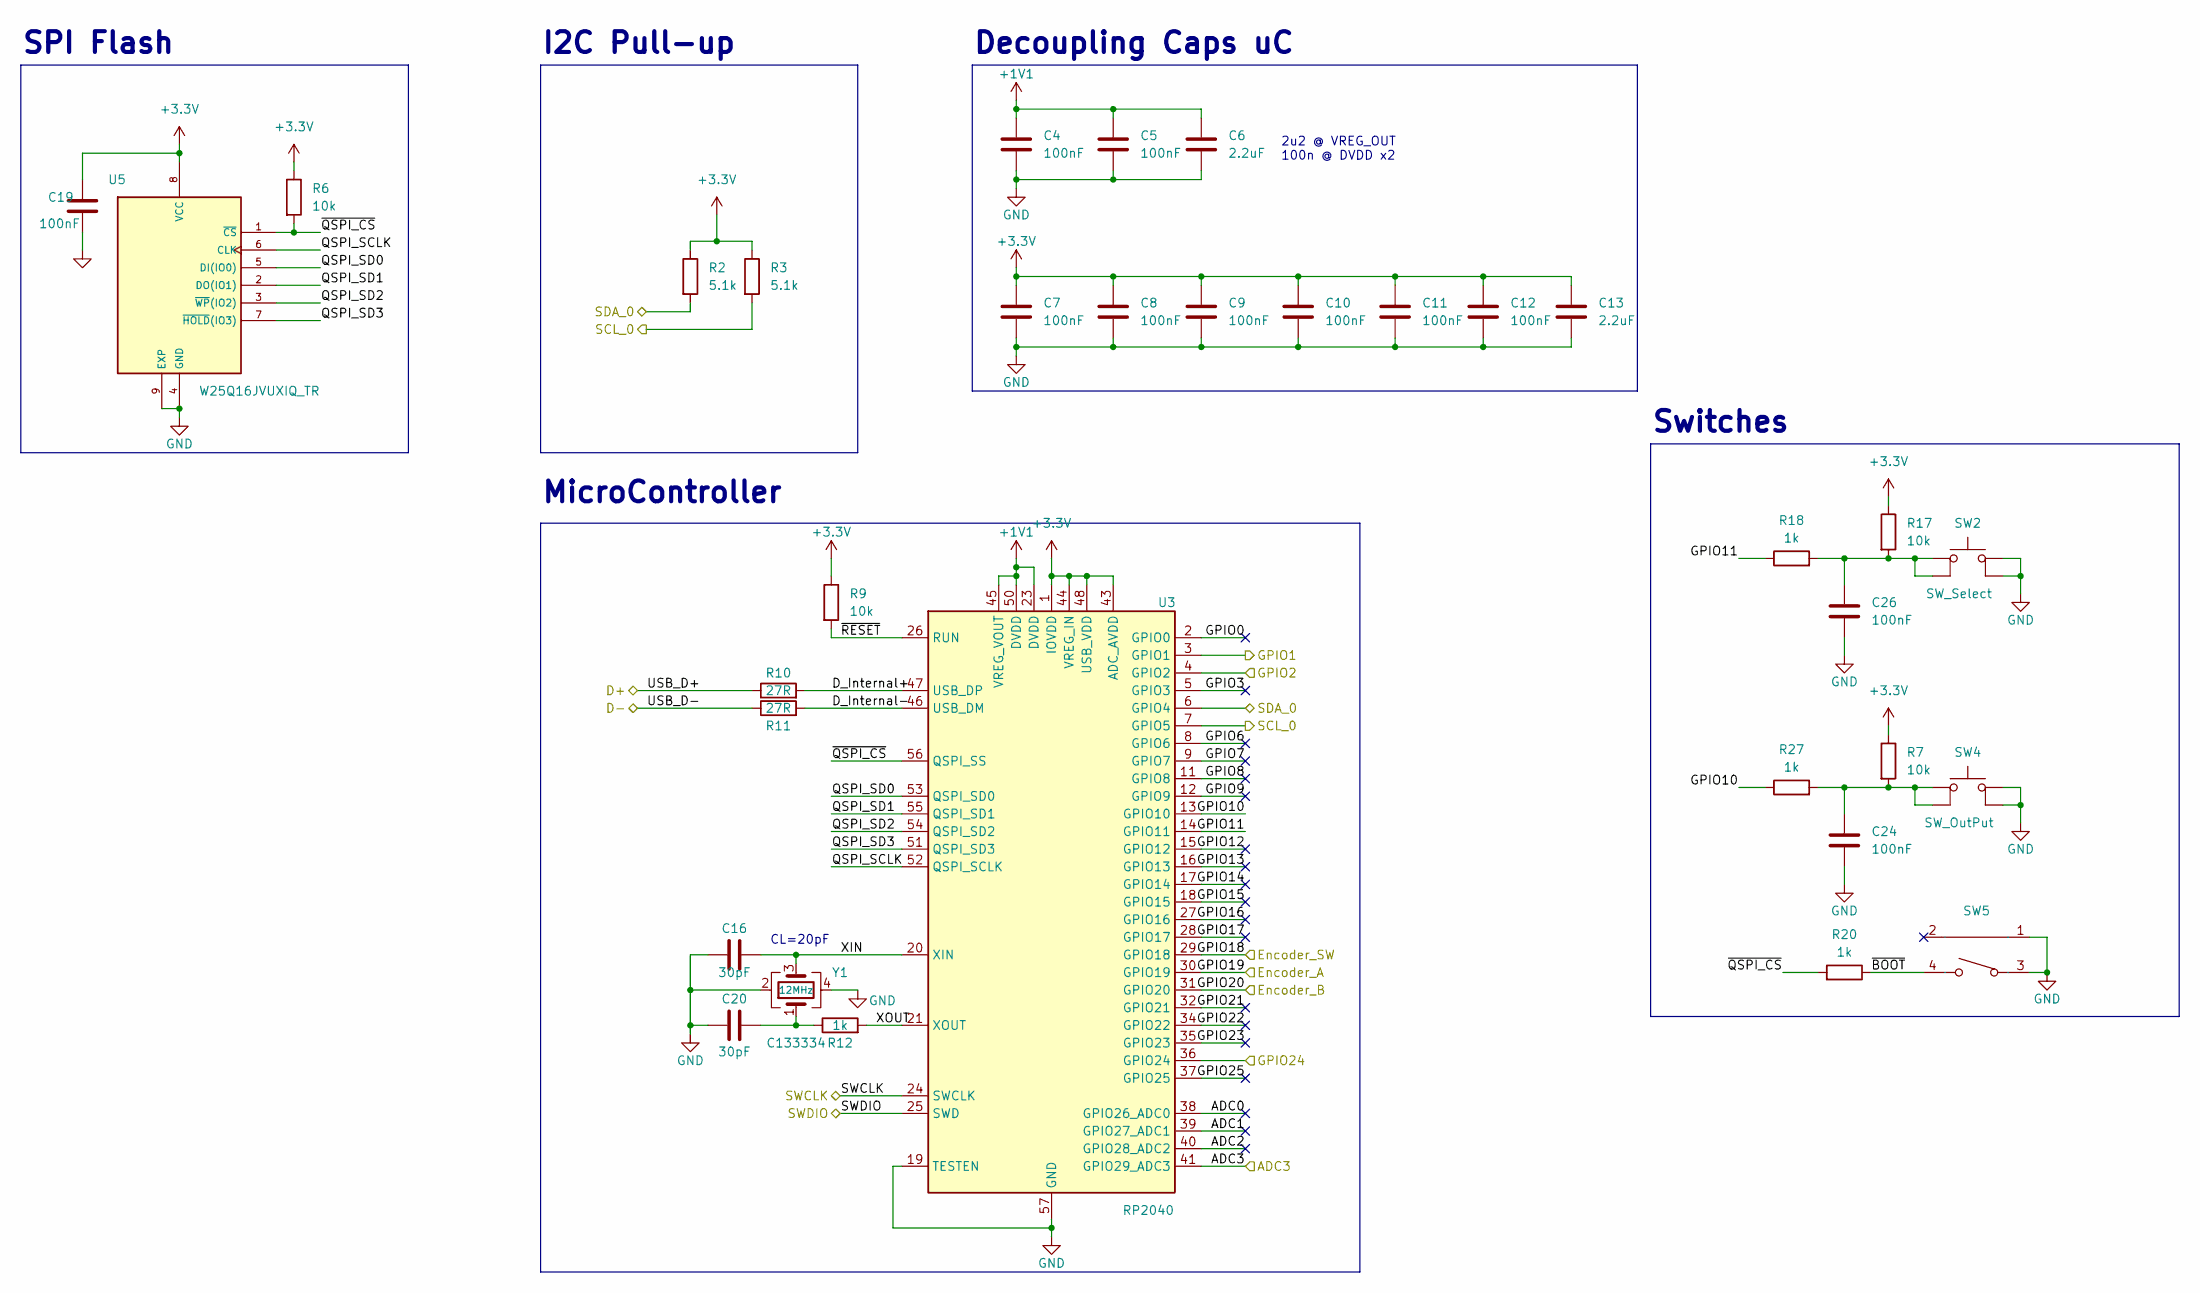
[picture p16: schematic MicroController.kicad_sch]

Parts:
C4, C5, C7, C8, C9, C10, C11, C12, C19, C24, C26: 100nF; C_0402_1005Metric; LCSC C1525
C6, C13: 2.2uF; C_0402_1005Metric; LCSC C12530
C16, C20: 30pF; C_0402_1005Metric; LCSC C1570
R2, R3: 5.1k; R_0402_1005Metric; LCSC C25905
R6, R7, R9, R17: 10k; R_0402_1005Metric; LCSC C25744
R10, R11: 27R; R_0402_1005Metric; LCSC C138021
R12, R18, R20, R27: 1k; R_0402_1005Metric; LCSC C11702
SW2: SW_Select; Button_6.2x6.2x12mm; LCSC C2762973
SW4: SW_OutPut; Button_6.2x6.2x12mm; LCSC C2762973
SW5: Button-SMD_TS24CA; LCSC C692458
U3: RP2040; QFN-56-1EP_7x7mm_P0.4mm_EP3.2x3.2mm; LCSC C2040
U5: W25Q16JVUXIQ_TR; 8-USON; PARTREV H; LCSC C2843335
Y1: 12MHz; Crystal_SMD_3225-4Pin_3.2x2.5mm; LCSC C133334

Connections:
+1V1: C4.1, C5.1, C6.1, U3.23 (DVDD), U3.45 (VREG_VOUT), U3.50 (DVDD)
+3.3V: C7.1, C8.1, C9.1, C10.1, C11.1, C12.1, C13.1, C19.1, R2.1, R3.1, R6.1, R7.1, R9.1, R17.1, U3.1 (IOVDD), U3.10 (IOVDD), U3.22 (IOVDD), U3.33 (IOVDD), U3.42 (IOVDD), U3.43 (ADC_AVDD), U3.44 (VREG_IN), U3.48 (USB_VDD), U3.49 (IOVDD), U5.8 (VCC); also elsewhere on the board
/MicroController/ADC0: U3.38 (GPIO26_ADC0)
/MicroController/ADC1: U3.39 (GPIO27_ADC1)
/MicroController/ADC2: U3.40 (GPIO28_ADC2)
/MicroController/ADC3: U3.41 (GPIO29_ADC3); also elsewhere on the board
/MicroController/D_Internal+: R10.2, U3.47 (USB_DP)
/MicroController/D_Internal-: R11.2, U3.46 (USB_DM)
/MicroController/GPIO0: U3.2 (GPIO0)
/MicroController/GPIO1: U3.3 (GPIO1); also elsewhere on the board
/MicroController/GPIO2: U3.4 (GPIO2); also elsewhere on the board
/MicroController/GPIO3: U3.5 (GPIO3)
/MicroController/GPIO6: U3.8 (GPIO6)
/MicroController/GPIO7: U3.9 (GPIO7)
/MicroController/GPIO8: U3.11 (GPIO8)
/MicroController/GPIO9: U3.12 (GPIO9)
/MicroController/GPIO10: R27.1, U3.13 (GPIO10)
/MicroController/GPIO11: R18.1, U3.14 (GPIO11)
/MicroController/GPIO12: U3.15 (GPIO12)
/MicroController/GPIO13: U3.16 (GPIO13)
/MicroController/GPIO14: U3.17 (GPIO14)
/MicroController/GPIO15: U3.18 (GPIO15)
/MicroController/GPIO16: U3.27 (GPIO16)
/MicroController/GPIO17: U3.28 (GPIO17)
/MicroController/GPIO18: U3.29 (GPIO18); also elsewhere on the board
/MicroController/GPIO19: U3.30 (GPIO19); also elsewhere on the board
/MicroController/GPIO20: U3.31 (GPIO20); also elsewhere on the board
/MicroController/GPIO21: U3.32 (GPIO21)
/MicroController/GPIO22: U3.34 (GPIO22)
/MicroController/GPIO23: U3.35 (GPIO23)
/MicroController/GPIO24: U3.36 (GPIO24); also elsewhere on the board
/MicroController/GPIO25: U3.37 (GPIO25)
/MicroController/QSPI_SCLK: U3.52 (QSPI_SCLK), U5.6 (CLK)
/MicroController/QSPI_SD0: U3.53 (QSPI_SD0), U5.5 (DI(IO0))
/MicroController/QSPI_SD1: U3.55 (QSPI_SD1), U5.2 (DO(IO1))
/MicroController/QSPI_SD2: U3.54 (QSPI_SD2), U5.3 (~WP(IO2))
/MicroController/QSPI_SD3: U3.51 (QSPI_SD3), U5.7 (~HOLD(IO3))
/MicroController/SWCLK: U3.24 (SWCLK); also elsewhere on the board
/MicroController/SWDIO: U3.25 (SWD); also elsewhere on the board
/MicroController/USB_D+: R10.1; also elsewhere on the board
/MicroController/USB_D-: R11.1; also elsewhere on the board
/MicroController/XIN: C16.1, U3.20 (XIN), Y1.3
/MicroController/XOUT: R12.2, U3.21 (XOUT)
/MicroController/~BOOT: R20.1, SW5.4
/MicroController/~QSPI_CS: R6.2, R20.2, U3.56 (QSPI_SS), U5.1 (~CS)
/MicroController/~RESET: R9.2, U3.26 (RUN)
/Power/SCL_0: R3.2, U3.7 (GPIO5); also elsewhere on the board
/Power/SDA_0: R2.2, U3.6 (GPIO4); also elsewhere on the board
GND: C4.2, C5.2, C6.2, C7.2, C8.2, C9.2, C10.2, C11.2, C12.2, C13.2, C16.2, C19.2, C20.2, C24.2, C26.2, SW2.3 (B), SW2.4 (A), SW4.3 (B), SW4.4 (A), SW5.1, SW5.3, U3.19 (TESTEN), U3.57 (GND), U5.4 (GND), U5.9 (EXP), Y1.2, Y1.4; also elsewhere on the board
unnamed: C20.1, R12.1, Y1.1
unnamed: C24.1, R7.2, R27.2, SW4.1 (A), SW4.2 (A)
unnamed: C26.1, R17.2, R18.2, SW2.1 (A), SW2.2 (A)

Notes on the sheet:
Decoupling Caps uC
I2C Pull-up
SPI Flash
MicroController
CL=20pF
Switches
2u2 @ VREG_OUT 100n @ DVDD x2

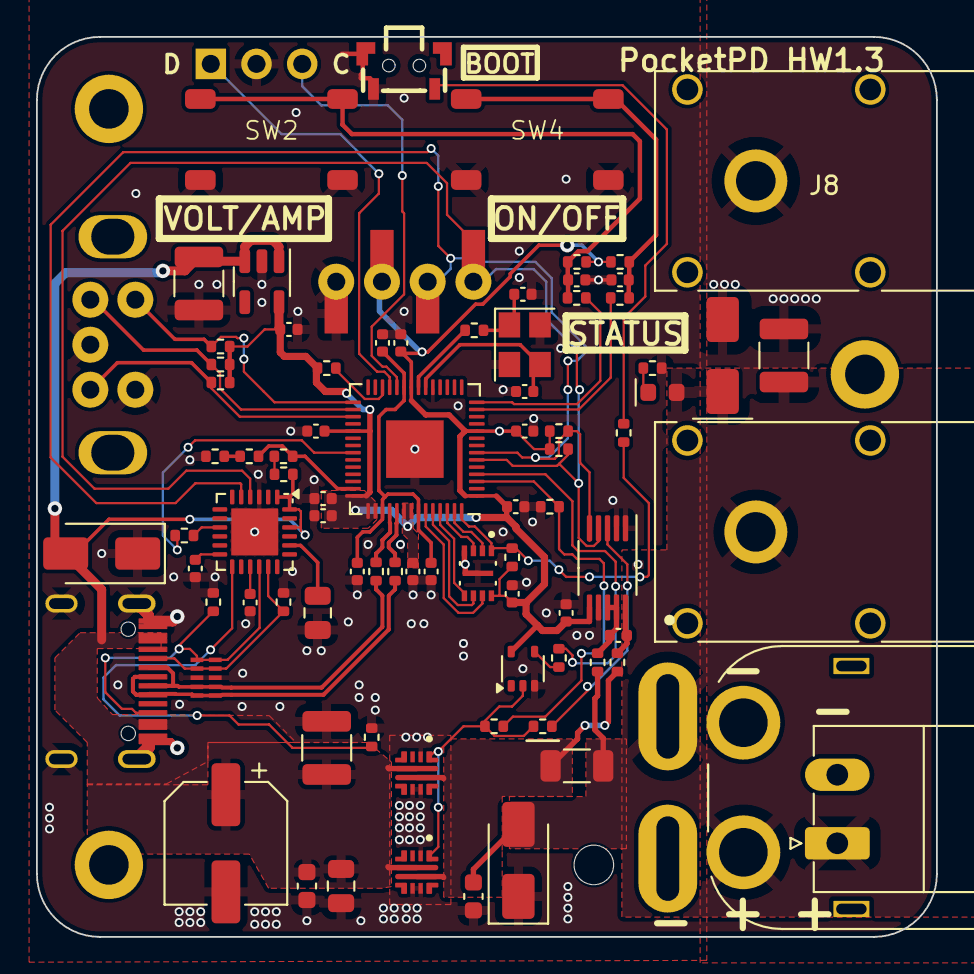
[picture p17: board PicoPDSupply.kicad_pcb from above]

Board: 2 copper layers, 50.0 x 50.0 mm, 89 parts (0 on the bottom side), 51 nets.

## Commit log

2025-06-29 Update 3D bottom, add 3D knob
    New 3D bottom has 0.4mm layer height for magnet area. Ensure easier printing.
    [3D Bottom.stl, 3D Knob.stl, 3D Top.stl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]
2025-11-22 Push HW1.2
    [3D Bottom.stl, 3D Knob.stl, 3D Top.stl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]
2025-11-22 Push HW1.3
    [Assembly_BOM.xlsx, Assembly_bom.csv, Bottom_Anderson-XT60.step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]
2026-01-02 Add KiCad files
    [Connection.kicad_sch, MicroController.kicad_sch, PicoPDSupply.kicad_pcb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]

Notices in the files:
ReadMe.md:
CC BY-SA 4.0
